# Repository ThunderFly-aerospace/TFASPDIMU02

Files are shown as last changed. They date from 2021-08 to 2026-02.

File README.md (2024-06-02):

# TFASPDIMU02 - Differential pressure sensor and IMU



ThunderFly TFASPDIMU02 is I2C bus sensor board equipped with a differential pressure sensor ([Sensirion SDP3x](https://www.sensirion.com/sdp3x/)) and 9-axis motion tracking sensor ([ICM-20948](https://invensense.tdk.com/products/motion-tracking/9-axis/icm-20948/)). The board is equipped with a 4-pin JST-GH connector. The sensor board is designed for multiple uses. It can be used as a self-adjusting anemometer [WINDGAUGE03](https://github.com/mlab-modules/WINDGAUGE03) or as an airspeed sensor for UAVs with optional function as the external magnetometer. The featured use (after firmware improvement) could be an angle of attract sensor, stall detector, or vibration (Flutter) detector.

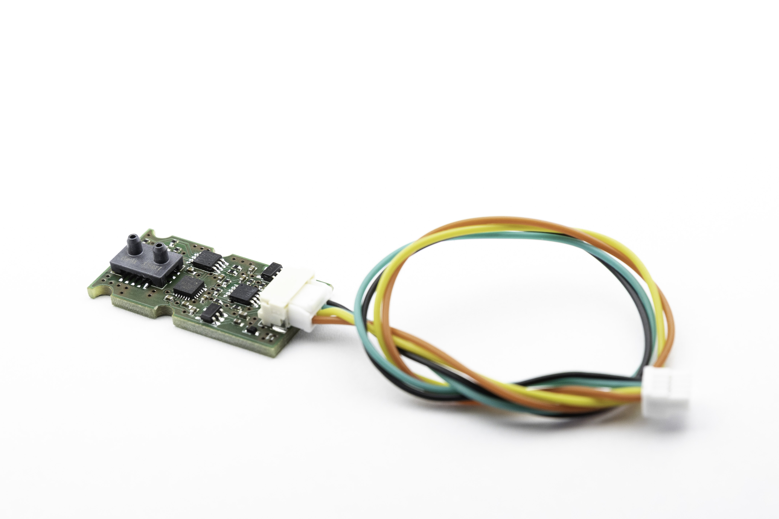
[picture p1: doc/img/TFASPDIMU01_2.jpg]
TFASPDIMU02 PCB


TFASPDIMU is commercially available from [ThunderFly s.r.o.](https://www.thunderfly.cz/), write an email to info@thunderfly.cz or shop at [Tindie store](https://www.tindie.com/stores/thunderfly/).

## Specification
 * Type: Differential and 9-axis motion sensor board
 * Mass: 3 g
 * Size: 30 x 15 mm
 * Power input: +5 V
 * Connection: 4pin JST-GH connector PixHawk compatible

**SDP3x differential pressure sensor**
 * Range: +/- 125/500/1500 Pa (depending on exact sensor type [SDP33 by default](https://sensirion.com/media/documents/6B7302AA/6375F33C/DP_DS_SDP33_D1.pdf))
 * Excellent accuracy and repeatability, even below one Pascal
 * No zero-point offset, no temperature drift
 * Calibrated and temperature-compensated
 * Fast sampling time of 2kHz at 16 bit resolution
 * I2C address: 0x21 (0d33), could be changed by JP2 and/or resorderig the R10 value.

 **ICM-20948 9-axis IMU unit**
 * 3-axis gyroscope, 3-axis accelerometer, 3-axis compass (magnetometer)
 * Onboard Digital Motion Processor (DMP)
 * On-chip 16-bit ADCs and Programmable Filters
 * 7 MHz SPI or 400 kHz Fast Mode I²C
 * Digital temperature sensor
 * Default I2C address: 0x68 (0d104), can be changed to 0x69 (0d105) by adjusting the JP1.

## Example of uses

### WINDGUAGE - weather vane sensor 

Ground control station anemometer [WINDGAUGE03](https://github.com/mlab-modules/WINDGAUGE03) is based on a TFASPDIMU sensor which is used for both wind direction and wind speed measurement. 

### TFSLOT01 - UAV airspeed sensor

Our [TFSLOT](https://github.com/ThunderFly-aerospace/TFSLOT01) sensor is an airspeed sensor for use mainly on UAVs. Due to the 3D printed case, optimizing housing according to the sensor's location on the UAV and tuning its characteristics is possible. The first use of this sensor was on our autogyro [TF-G2](https://github.com/ThunderFly-aerospace/TF-G2/).

TFSLOT01 sensor

More details about this solution are available in the repository [TFSLOT01](https://github.com/ThunderFly-aerospace/TFSLOT01).

### TFPIPE01 - UAV airspeed sensor

The symmetric variant of TFSLOT sensor for different mounting options [TFPIPE01](https://github.com/ThunderFly-aerospace/TFPIPE01).

### TFVENTUFO - innovative anemometer

This anemometer is also based on the venturi effect. Thanks to a clever design, it will measure the wind speed from all directions (without knowing the direction).

### Angle of Attack sensor

In case of mounting on slip-ring bearing the sensor could sense air AoA of the vehicle.

### Stall detector

The venturi geometry could also be inverted therefore the pressure ports look in open airflow. That results in the ability to detect stalls on wings by detecting the absence of pressure difference and increasing pressure fluctuations on the wing surface. 

## Hardware

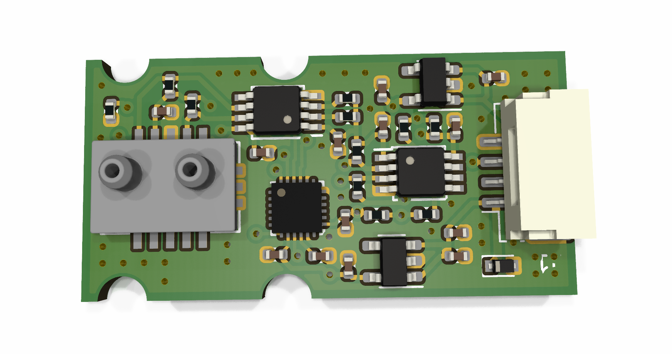
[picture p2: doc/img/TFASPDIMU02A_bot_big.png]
TFASPDIMU02 PCB


### Electronics schema

Full schema is available in [PDF](/hw/sch_pcb/TFASPDIMU02A.pdf)
TFASPDIMU02 schema

### PCB dimensions

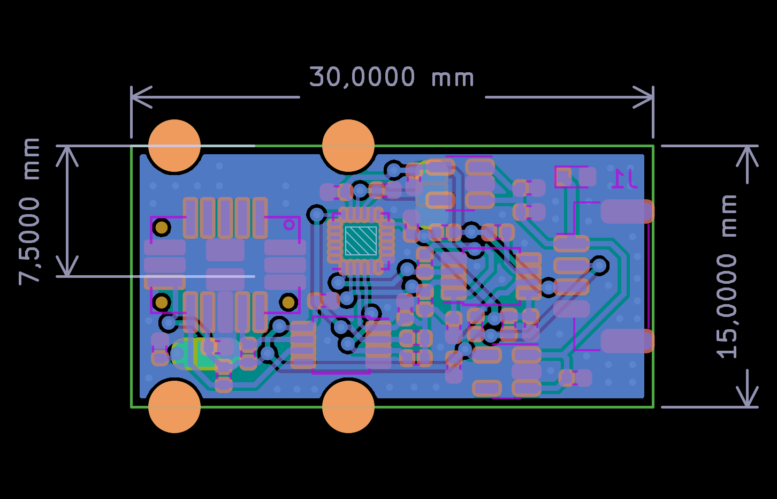
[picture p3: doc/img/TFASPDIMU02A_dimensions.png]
TFASPDIMU02 dimensions


Pressure sensor connections are aligned to the center of the PCB width.

### I2C connector pinout

|Signal | Pixhawk Color | ThunderFly color |
|---|---|---|
| +5V  | Red | red Red |
| SCL  | Black |  yellow Yellow |
| SDA  | Black |  green Green |
| GND | Black | black Black |

> Pixhawk pinout is listed according to the [Pixhawk connector standard](https://github.com/pixhawk/Pixhawk-Standards/blob/master/DS-009%20Pixhawk%20Connector%20Standard.pdf).

#### PixHawk autopilot connection cable

To increase the transmission quality, it is mandatory to create twisted pairs of SDA, GND, and SCL,+5V on the cable (as shown in the image)

- 10 twists for each pair  SCL/+5V and SDA/GND per 30cm cable length
- 4 turns/twists of pairs per 30cm cable length.

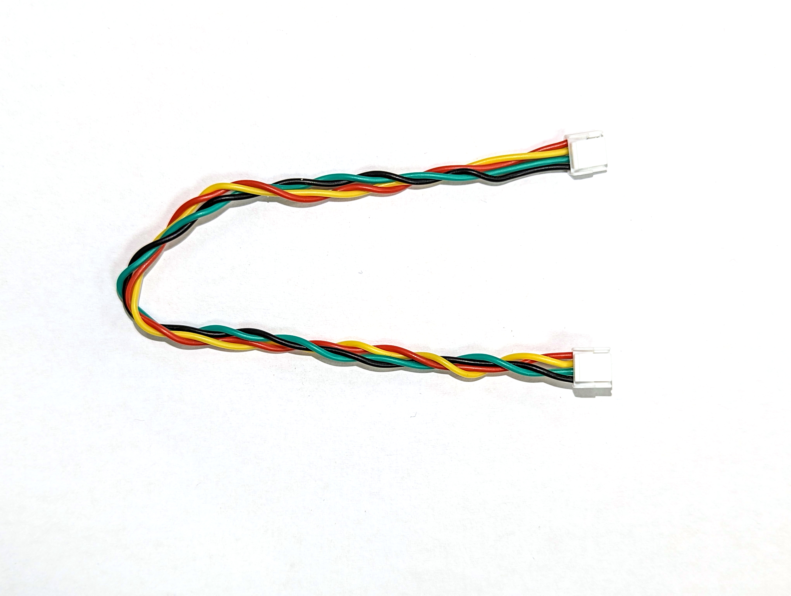
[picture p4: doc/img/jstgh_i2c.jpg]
ThunderFly I2C jstgh


## Usage

### Python
For reading data from the sensor, we have prepared a Python script in the [PyMLAB](https://github.com/MLAB-project/pymlab) library that uses the pySMBus to read data. It can be used directly from a computer with a corresponding converter (for example MLAB [USBI2C01A](https://wiki.mlab.cz/doku.php?id=cs:usbi2c)) or with one-board computers (Odroid, raspberry, and similar) that have own smbus output.

#### Calibration verification

Calibration can be verified by mounting an anemometer to the car roof and comparing it to GNSS speed. This needs to be done in windless weather.

### PX4

> There exists a [pull-request of modified SDP33 driver into PX4 stack](https://github.com/PX4/PX4-Autopilot/pull/18593).

The main use of this sensor is as an airspeed sensor. It can also be used as an external magnetometer and thermometer.

### Ardupilot

We are currently unable to implement the sensor in the Ardupilot flight stack. However, we will be happy to assist with implementation. You can [contact us](https://www.thunderfly.cz/contact-us.html)

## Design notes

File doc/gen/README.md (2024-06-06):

# PCB

Board size: 30.0x15.0 mm (1.18x0.59 inches)

- This is the size of the rectangle that contains the board
- Thickness: 1.6 mm (63 mils)
- Material: FR4
- Finish: HAL lead-free
- Layers: 2
- Copper thickness: 35 µm

Solder mask: TOP / BOTTOM

- Color: Green

Silk screen: TOP / BOTTOM

- Color: White

Stackup:

| Name | Type | Color | Thickness | Material | Epsilon_r | Loss tangent |
|---|---|---|---|---|---|---|
| F.SilkS | Top Silk Screen | | | | | |
| F.Paste | Top Solder Paste | | | | | |
| F.Mask | Top Solder Mask | Green | 10 | | | |
| F.Cu | copper | | 35 | | | |
| dielectric 1 | core | | 1510 | FR4 | 4.5 | 0.020 |
| B.Cu | copper | | 35 | | | |
| B.Mask | Bottom Solder Mask | Green | 10 | | | |
| B.Paste | Bottom Solder Paste  | | | | | |
| B.SilkS | Bottom Silk Screen | | | | | |

# Important sizes

Clearance: 0.2 mm (8 mils)

Track width: 0.2 mm (8 mils)

- By design rules: 0.2 mm (8 mils)

Drill: 0.5 mm (20 mils)

- Vias: 0.5 mm (20 mils) [Design: 0.4 mm (16 mils)]
- Pads: 0.7 mm (28 mils)
- The above values are real drill sizes, they add 0.1 mm (4 mils) to plated holes (PTH)

Via: 0.8/0.4 mm (31/16 mils)

- By design rules: 0.8/0.3 mm (31/12 mils)
- Micro via: yes [0.2/0.1 mm (8/4 mils)]
- Buried/blind via: yes
- Total: 70 (thru: 70 buried/blind: 0 micro: 0)

Outer Annular Ring: 0.15 mm (6 mils)

- By design rules: N/A mm (N/A mils)

Eurocircuits class: 4B
- Using min drill 0.5 mm for an OAR of 0.15 mm

# General stats

Components count: (SMD/THT)

- Top: 0/4 (THT)
- Bottom: 36/0 (SMD)

Defined tracks:

- 0.2 mm (8 mils)
- 0.3 mm (12 mils)
- 0.4 mm (16 mils)
- 0.5 mm (20 mils)
- 0.6 mm (24 mils)
- 0.7 mm (28 mils)
- 0.8 mm (31 mils)

Used tracks:

- 0.2 mm (8 mils) (39) defined: yes
- 0.3 mm (12 mils) (184) defined: yes
- 0.4 mm (16 mils) (23) defined: yes
- 0.5 mm (20 mils) (3) defined: yes

Defined vias:

Used vias:

- 0.8/0.4 mm (31/16 mils) (Count: 70, Aspect: 2.0 A) defined: no

Holes (excluding vias):

- 0.7 mm (28 mils) (3)
- 3.0 mm (118 mils) (4)

Oval holes:

Drill tools (including vias and computing adjusts and rounding):

- 0.5 mm (20 mils) (70)
- 0.7 mm (28 mils) (3)
- 3.0 mm (118 mils) (4)

Solder paste stats:

Using a paste with 87.75 % alloy, that has an specific gravity for the alloy of 7.4 g/cm³
and 1.0 g/cm³ for the flux. This paste has an specific gravity of  4.15 g/cm³.

The stencil thickness is  0.12 mm.

| Side | Pads with paste | Area [mm²] | Paste [g] |
|---|---|---|---|
| Total  | 128 | 65.00 | 0.32 |

Note: this is just an approximation to the theoretical value. Margins of the solder mask and waste aren't computed.

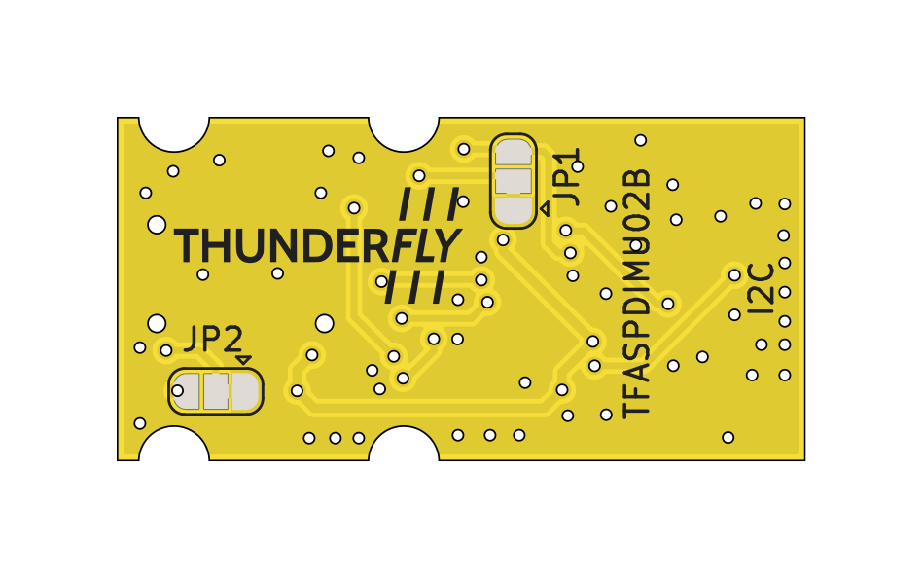
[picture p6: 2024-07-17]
doc/gen/img/TFASPDIMU02-top.png

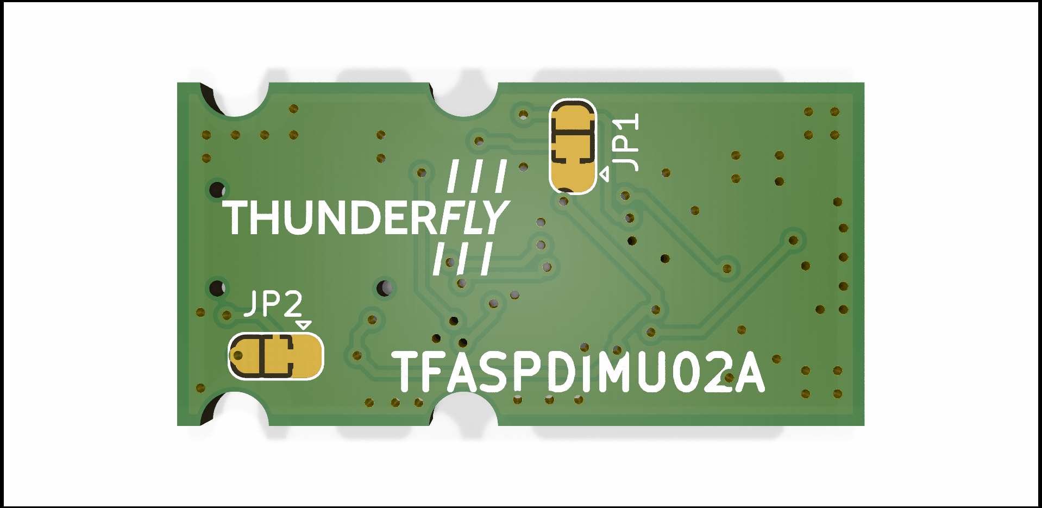
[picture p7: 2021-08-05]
doc/img/TFASPDIMU02A_top_big.png

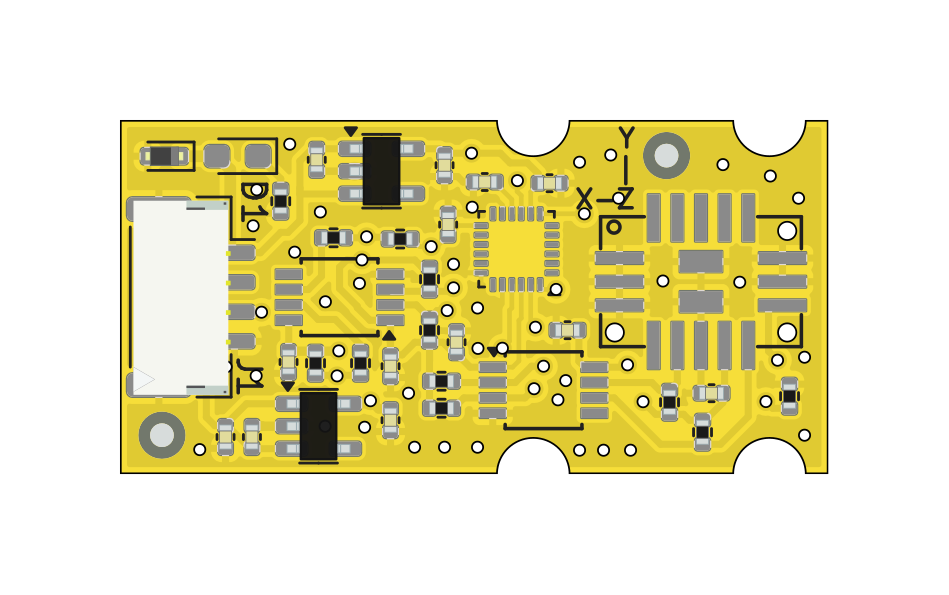
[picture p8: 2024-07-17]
doc/gen/img/TFASPDIMU02-bottom.png

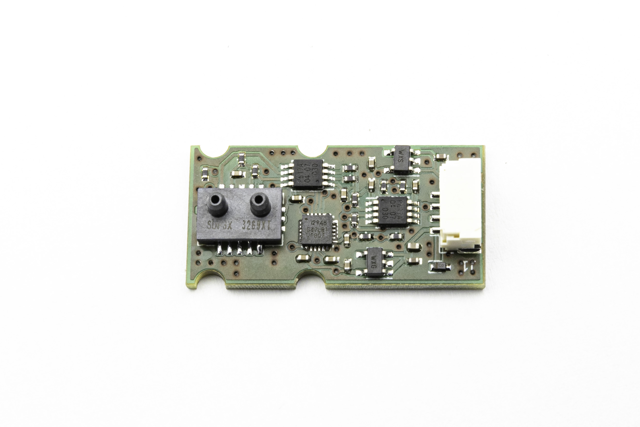
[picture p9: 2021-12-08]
doc/img/TFASPDIMU01_3.jpg

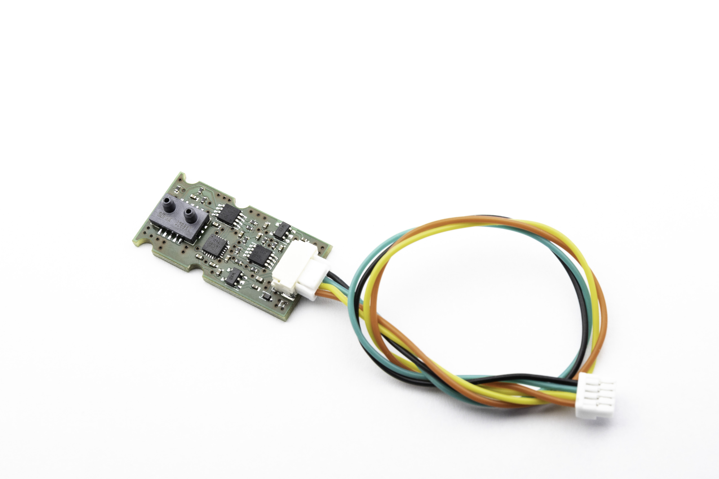
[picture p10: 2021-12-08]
doc/img/TFASPDIMU01_1.jpg

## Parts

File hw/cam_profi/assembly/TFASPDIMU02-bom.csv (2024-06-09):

Component | Description | Part | References | Value | Footprint | Quantity Per PCB | Datasheet | ust_id
1 | Unpolarized capacitor | C | C1C2C3C4C9C10C12C13 | 100nF | C_0402_1005Metric | 8 | ~ | 5c70984812875079b91f8bdb
2 | Unpolarized capacitor | C | C5C6C7C8 | 1uF | C_0402_1005Metric | 4 | ~ | 610cff5e1287500165a96ff9
3 | Unpolarized capacitor | C | C11 | 10uF | C_0402_1005Metric | 1 | ~ | 610d01671287500165a97012
4 |  | D_ZENER | D2 | BZX585-B5V6.115 | D_SOD-523 | 1 |  | 60879d38128750769ee58e48
5 | Light emitting diode | LED | D1 | GREEN | LED_0603_1608Metric_Pad1.05x0.95mm_HandSolder | 1 | https://trgkey.com/sites/default/files/data-sheet/FYLS-0603UGC-6241.pdf | 60d582331287500165f859d0
6 | 1x05 2.54 mm pitch header | SM04B-GHS-TB | J1 | SM04B-GHS-TB | JST_GH_SM04B-GHS-TB_1x04-1MP_P1.25mm_Horizontal | 1 |  | 5c86273d1287500b4e0280be
7 | Resistor | R | R1R11 | 75R | R_0402_1005Metric | 2 | ~ | 610d02e21287500165a97051
8 | Resistor | R | R12 | 180R | R_0402_1005Metric | 1 | ~ | 66660d02fb0c4b90204330d4
9 | Resistor | R | R2R3R10 | 2k7 | R_0402_1005Metric | 3 | ~ | 610d02801287500165a9703c
10 | Resistor | R | R4R5R6R7R8R9 | 10k | R_0402_1005Metric | 6 | ~ | 5c70984512875079b91f894c
11 | InvenSense 9-Axis Motion Sensor, Accelerometer, Gyroscope, Compass, I2C/SPI, QFN-24 | ICM-20948 | U2 | ICM-20948 | InvenSense_QFN-24_3x3mm_P0.4mm | 1 | http://www.invensense.com/wp-content/uploads/2016/06/DS-000189-ICM-20948-v1.3.pdf | 5c725a431287500b4e112ef5
12 | 300mA Low-dropout Voltage Regulator, Vout 1.8V, Vin up to 5.5V, SOT-23 | MIC5504-1.8YM5 | U5 | MIC5504-1.8YM5-TR | SOT-23-5 | 1 | http://ww1.microchip.com/downloads/en/DeviceDoc/MIC550X.pdf | 5c7256781287500b4e112eba
13 | 300mA Low-dropout Voltage Regulator, Vout 3.3V, Vin up to 5.5V, SOT-23 | MIC5504-3.3YM5 | U4 | MIC5504-3.3YM5-TR | SOT-23-5 | 1 | http://ww1.microchip.com/downloads/en/DeviceDoc/MIC550X.pdf | 5c7255e81287500b4e112ea2
14 | Level-Translating I2C Bus Buffer/Repeater, TSSOP-8 | PCA9617A | U3U6 | PCA9617A | TSSOP-8_3x3mm_P0.65mm | 2 | https://www.nxp.com/docs/en/data-sheet/PCA9617A.pdf | 610d03ad1287500165a97076
15 |  | SDP3x | U1 | SDP3x | SDP3x | 1 | https://docs.rs-online.com/3cff/0900766b81643b7b.pdf | 5e32e1111287502a337d0b08

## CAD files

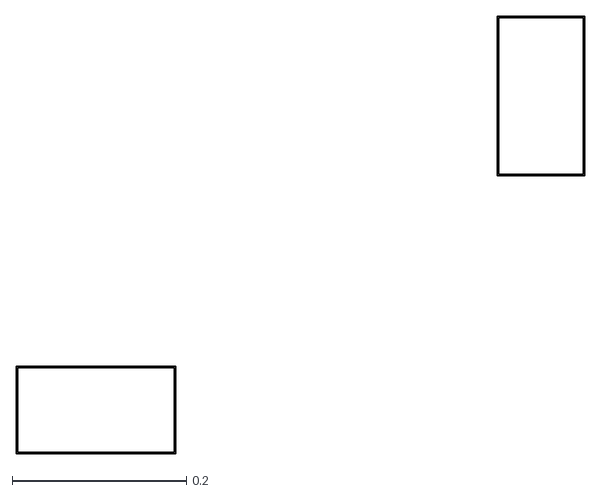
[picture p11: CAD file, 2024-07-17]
doc/gen/dxf/TFASPDIMU02-F_Courtyard.dxf
0.652 x 0.502

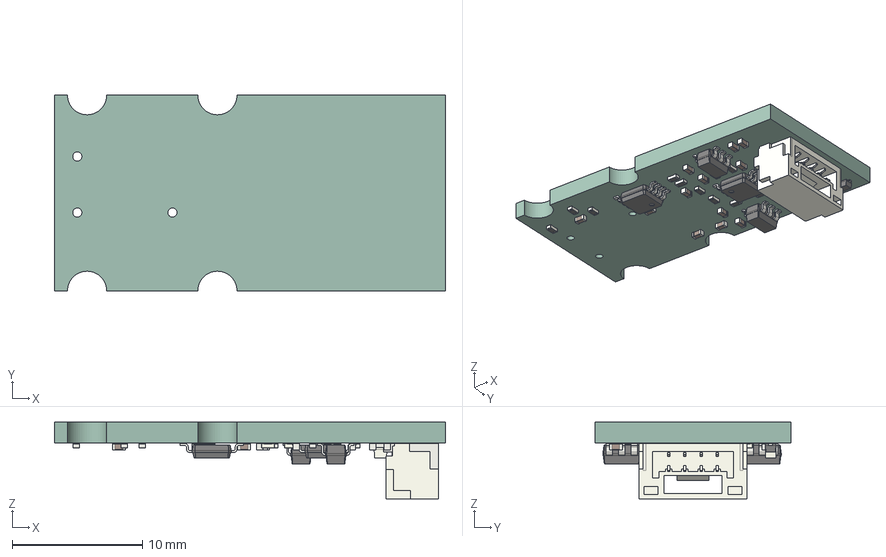
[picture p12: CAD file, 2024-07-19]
doc/gen/TFASPDIMU02.step
30.0 x 15.0 x 5.89 mm
C_0402_1005Metric x 13
R_0402_1005Metric x 12
D_SOD_523
TSSOP_8_3x3mm_P065mm x 2
LED_0603_1608Metric
JST_SM04B_GHS_TB
SOT_23_5 x 2
kibot_pvs4hcoh_PCB

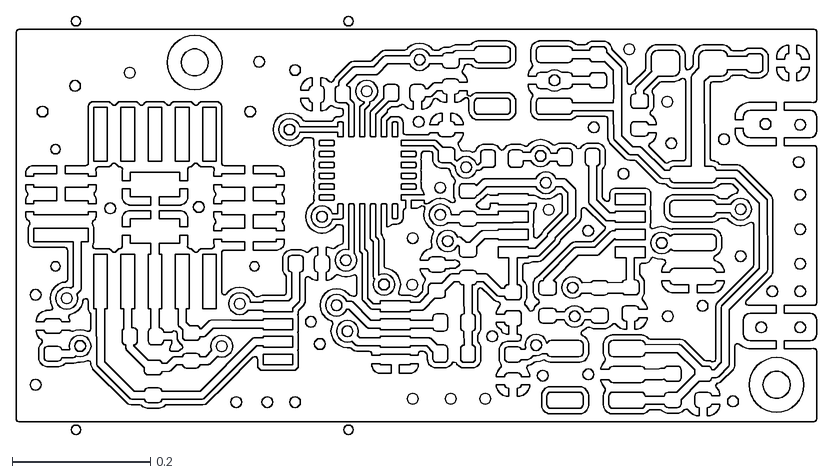
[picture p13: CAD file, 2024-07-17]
doc/gen/dxf/TFASPDIMU02-B_Cu.dxf
1.16 x 0.604

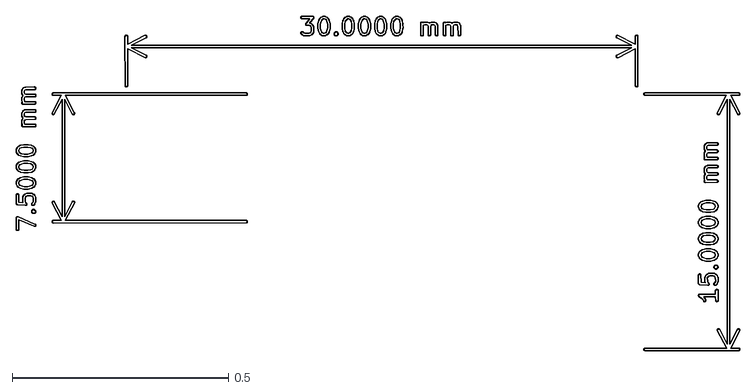
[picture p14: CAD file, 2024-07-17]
doc/gen/dxf/TFASPDIMU02-User_Drawings.dxf
1.67 x 0.773

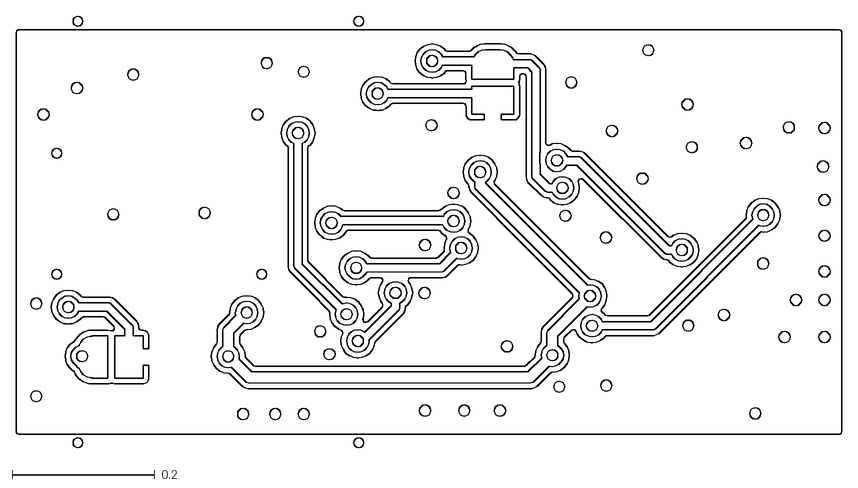
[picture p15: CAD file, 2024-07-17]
doc/gen/dxf/TFASPDIMU02-F_Cu.dxf
1.16 x 0.604

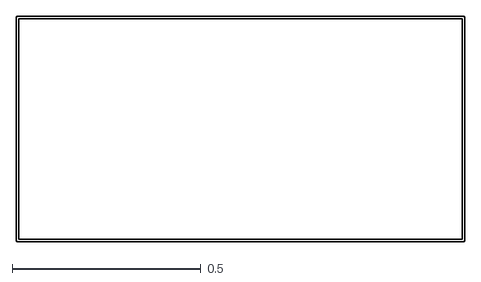
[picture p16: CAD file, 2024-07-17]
doc/gen/dxf/TFASPDIMU02-Edge_Cuts.dxf
1.19 x 0.596

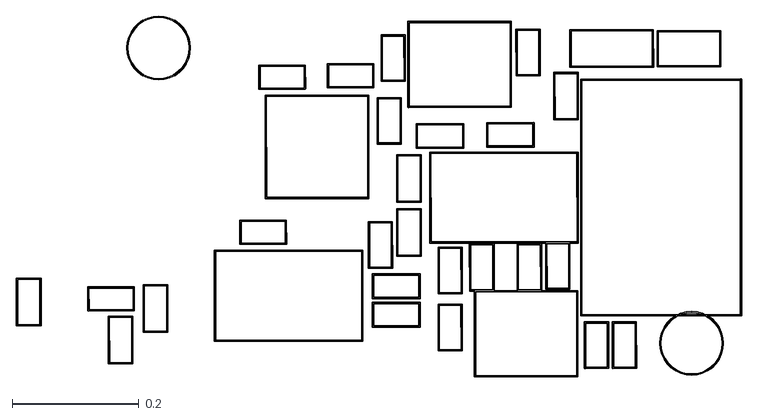
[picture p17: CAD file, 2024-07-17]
doc/gen/dxf/TFASPDIMU02-B_Courtyard.dxf
1.14 x 0.569

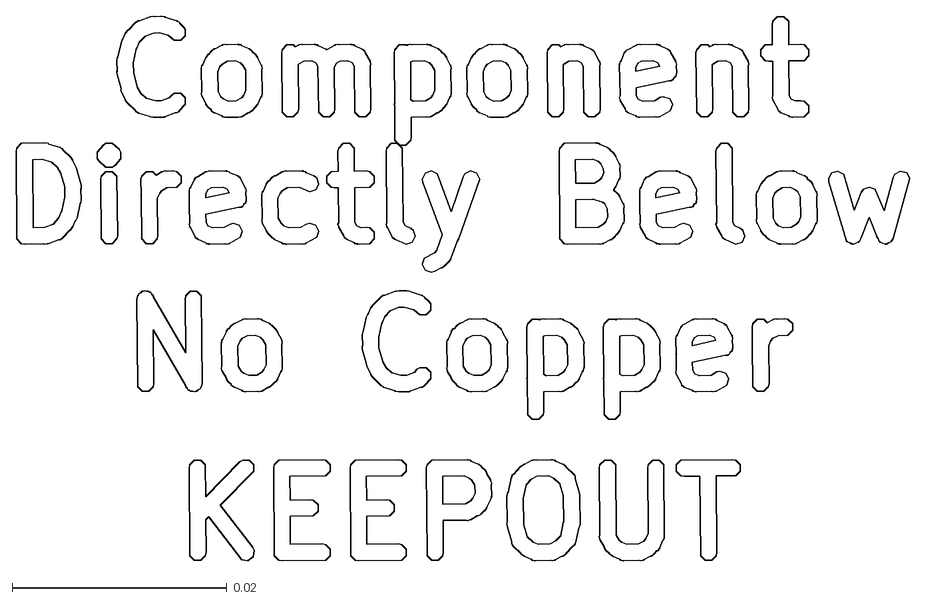
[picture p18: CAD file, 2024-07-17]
doc/gen/dxf/TFASPDIMU02-User_Comments.dxf
0.0833 x 0.0508

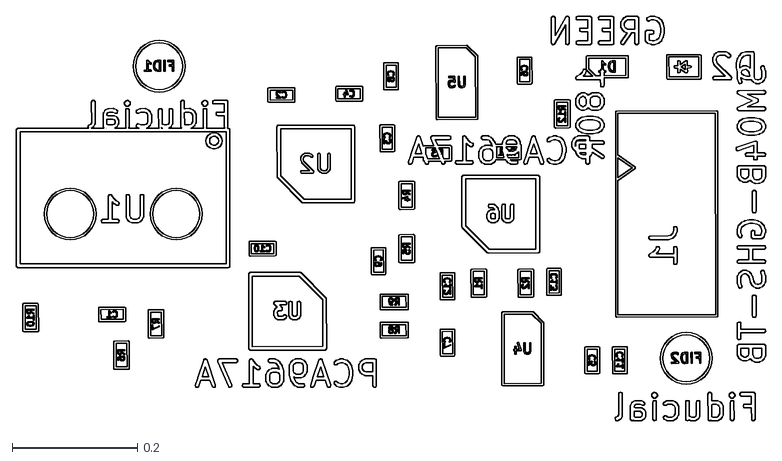
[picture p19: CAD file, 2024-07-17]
doc/gen/dxf/TFASPDIMU02-B_Fab.dxf
1.20 x 0.645

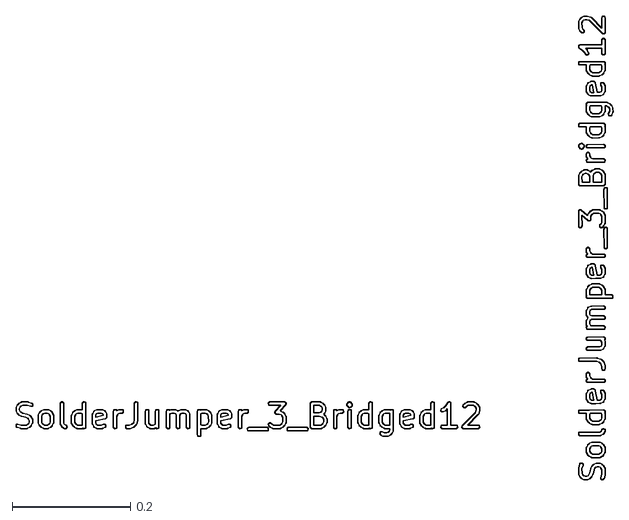
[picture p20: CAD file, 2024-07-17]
doc/gen/dxf/TFASPDIMU02-F_Fab.dxf
1.01 x 0.786

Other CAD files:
doc/gen/dxf/TFASPDIMU02-B_Adhesive.dxf
doc/gen/dxf/TFASPDIMU02-User_Eco2.dxf
doc/gen/dxf/TFASPDIMU02-F_Adhesive.dxf
doc/gen/dxf/TFASPDIMU02-Margin.dxf
doc/gen/dxf/TFASPDIMU02-User_Eco1.dxf
doc/gen/dxf/TFASPDIMU02-B_Mask.dxf
doc/gen/dxf/TFASPDIMU02-B_Paste.dxf
doc/gen/dxf/TFASPDIMU02-B_Silkscreen.dxf
doc/gen/dxf/TFASPDIMU02-F_Mask.dxf
doc/gen/dxf/TFASPDIMU02-F_Paste.dxf
doc/gen/dxf/TFASPDIMU02-F_Silkscreen.dxf

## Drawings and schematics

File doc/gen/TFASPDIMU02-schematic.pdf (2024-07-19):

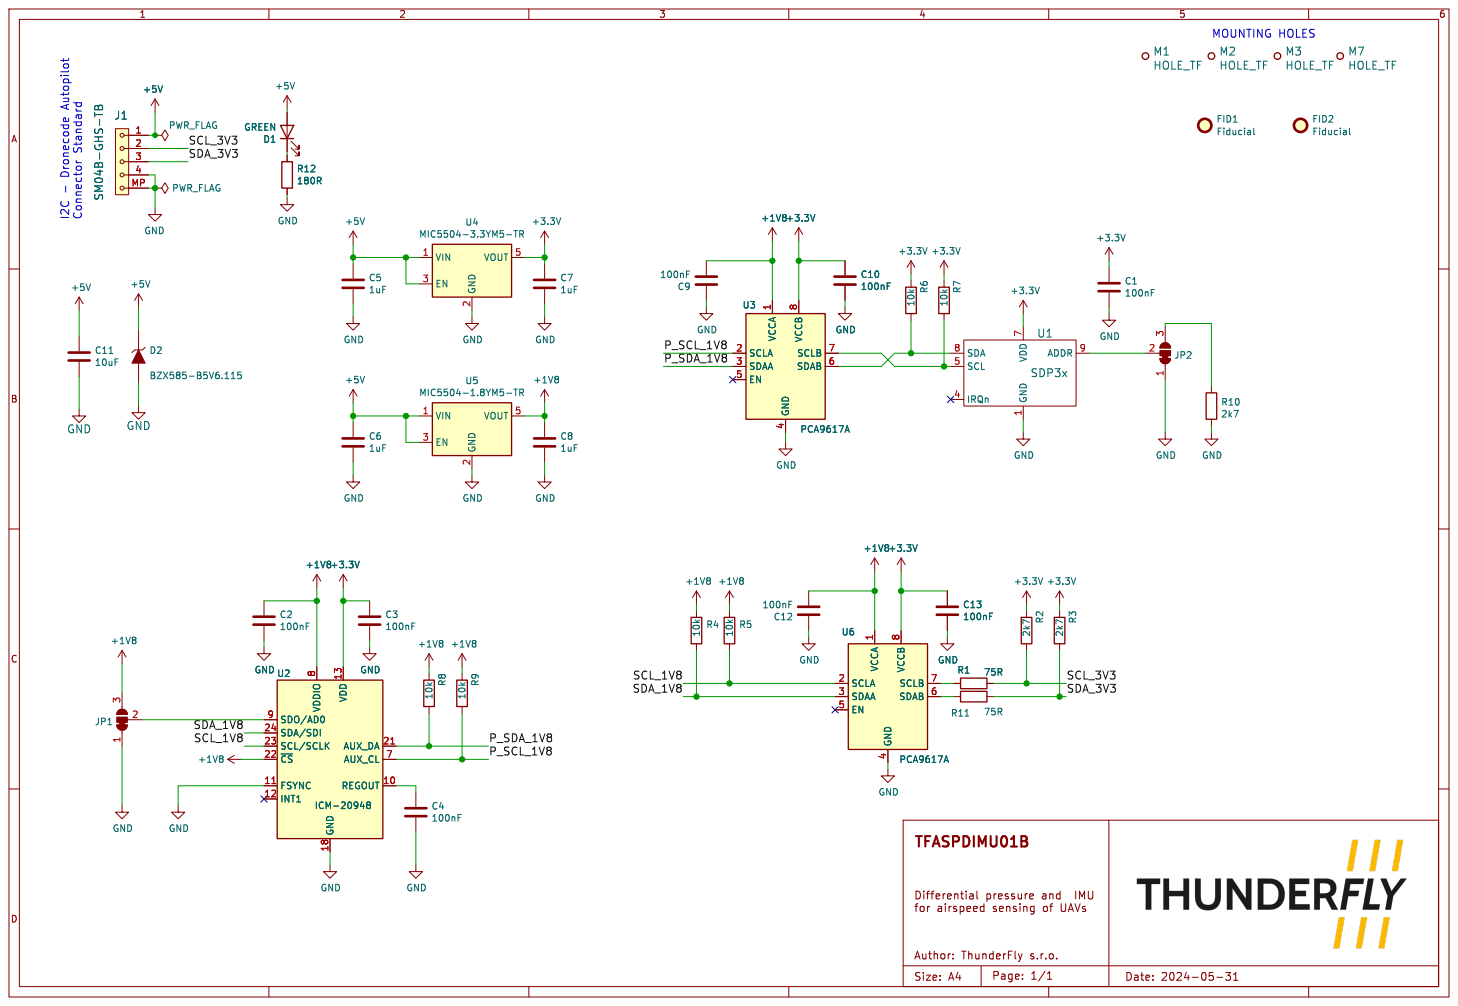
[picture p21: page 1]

4 EN 5 SDAB 6 SCLB 7 VCCB U3 8 PCA9617A

4 EN 5 SDAB 6 SCLB 7 VCCB

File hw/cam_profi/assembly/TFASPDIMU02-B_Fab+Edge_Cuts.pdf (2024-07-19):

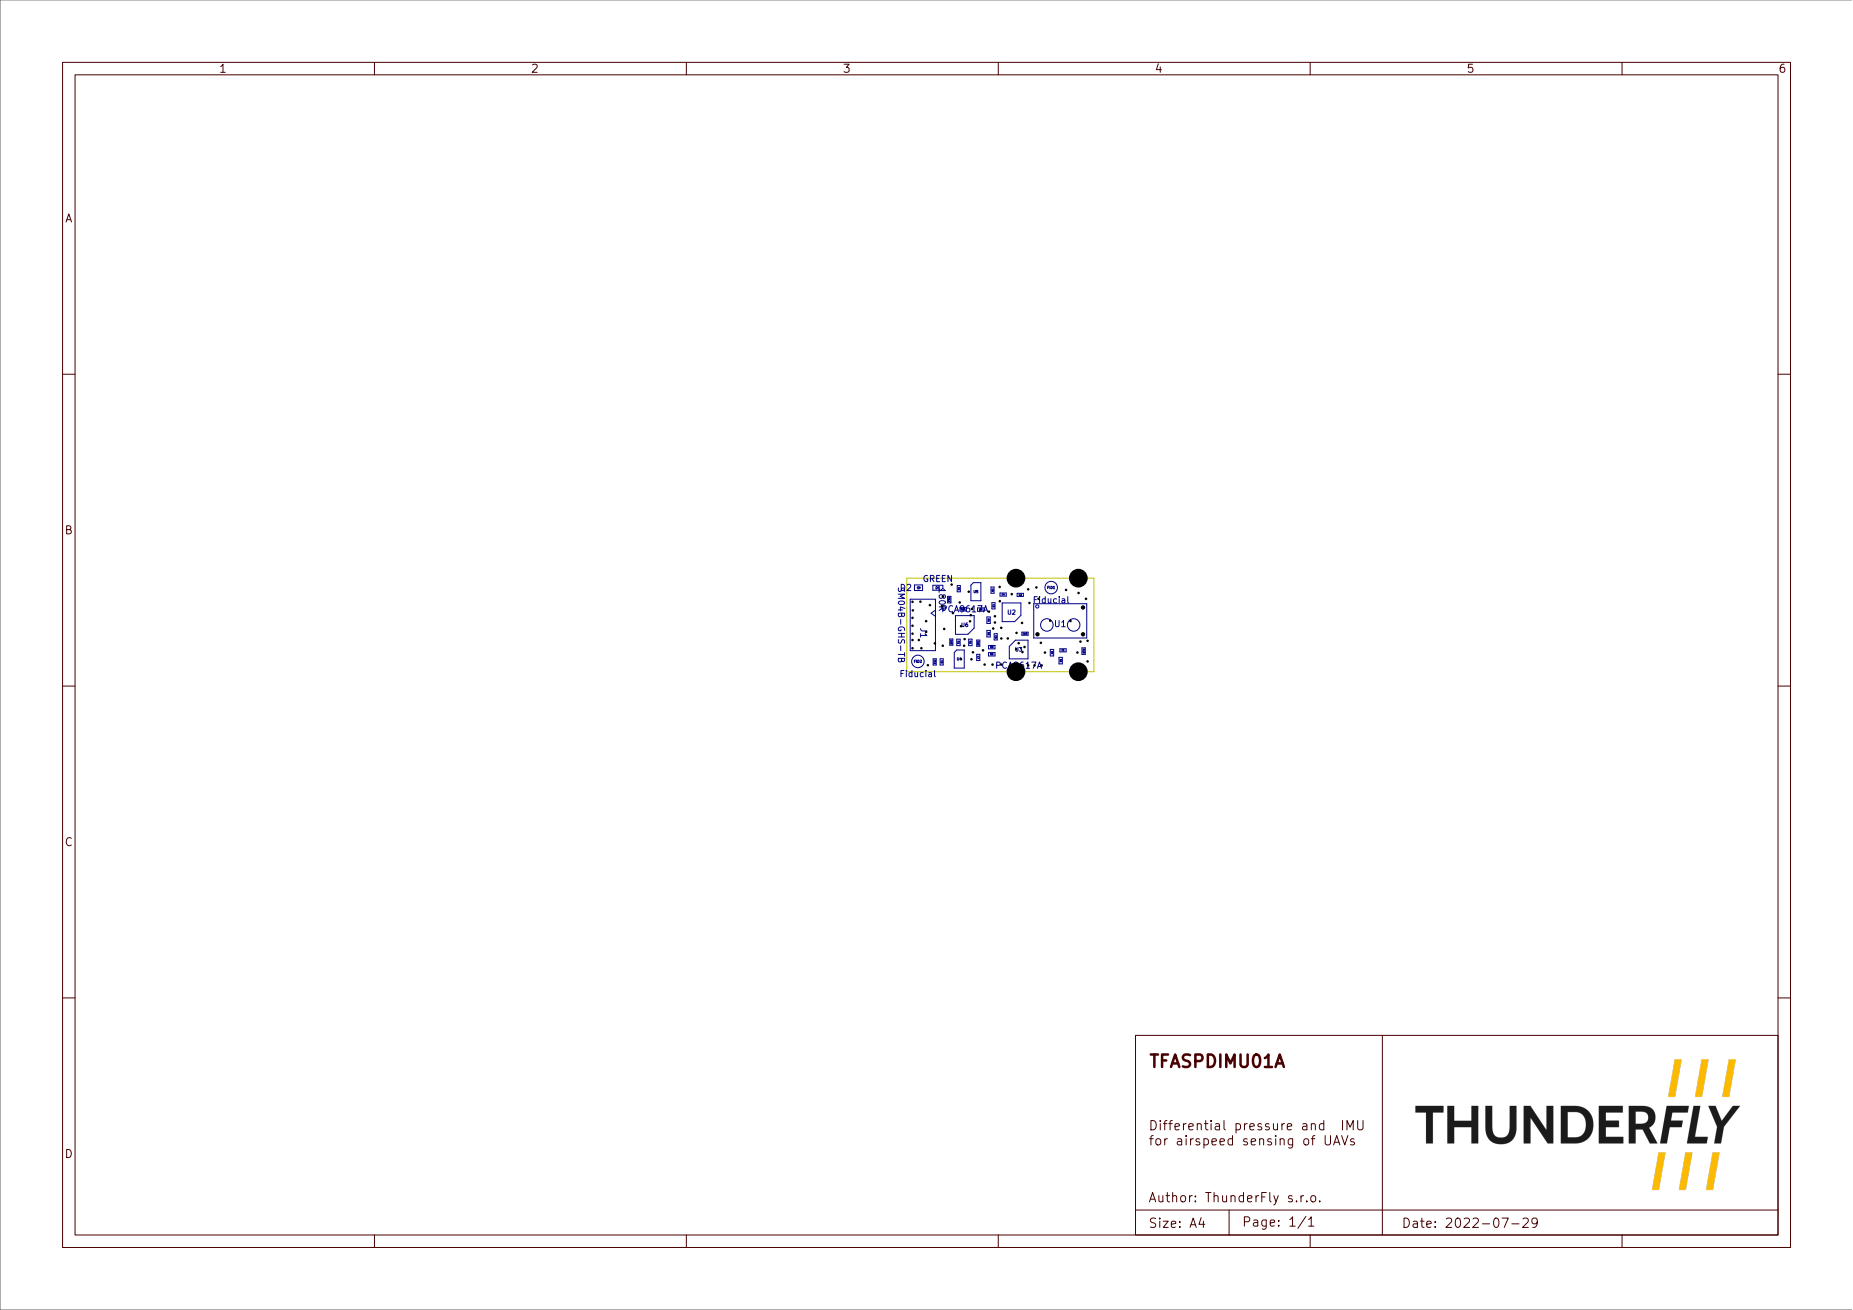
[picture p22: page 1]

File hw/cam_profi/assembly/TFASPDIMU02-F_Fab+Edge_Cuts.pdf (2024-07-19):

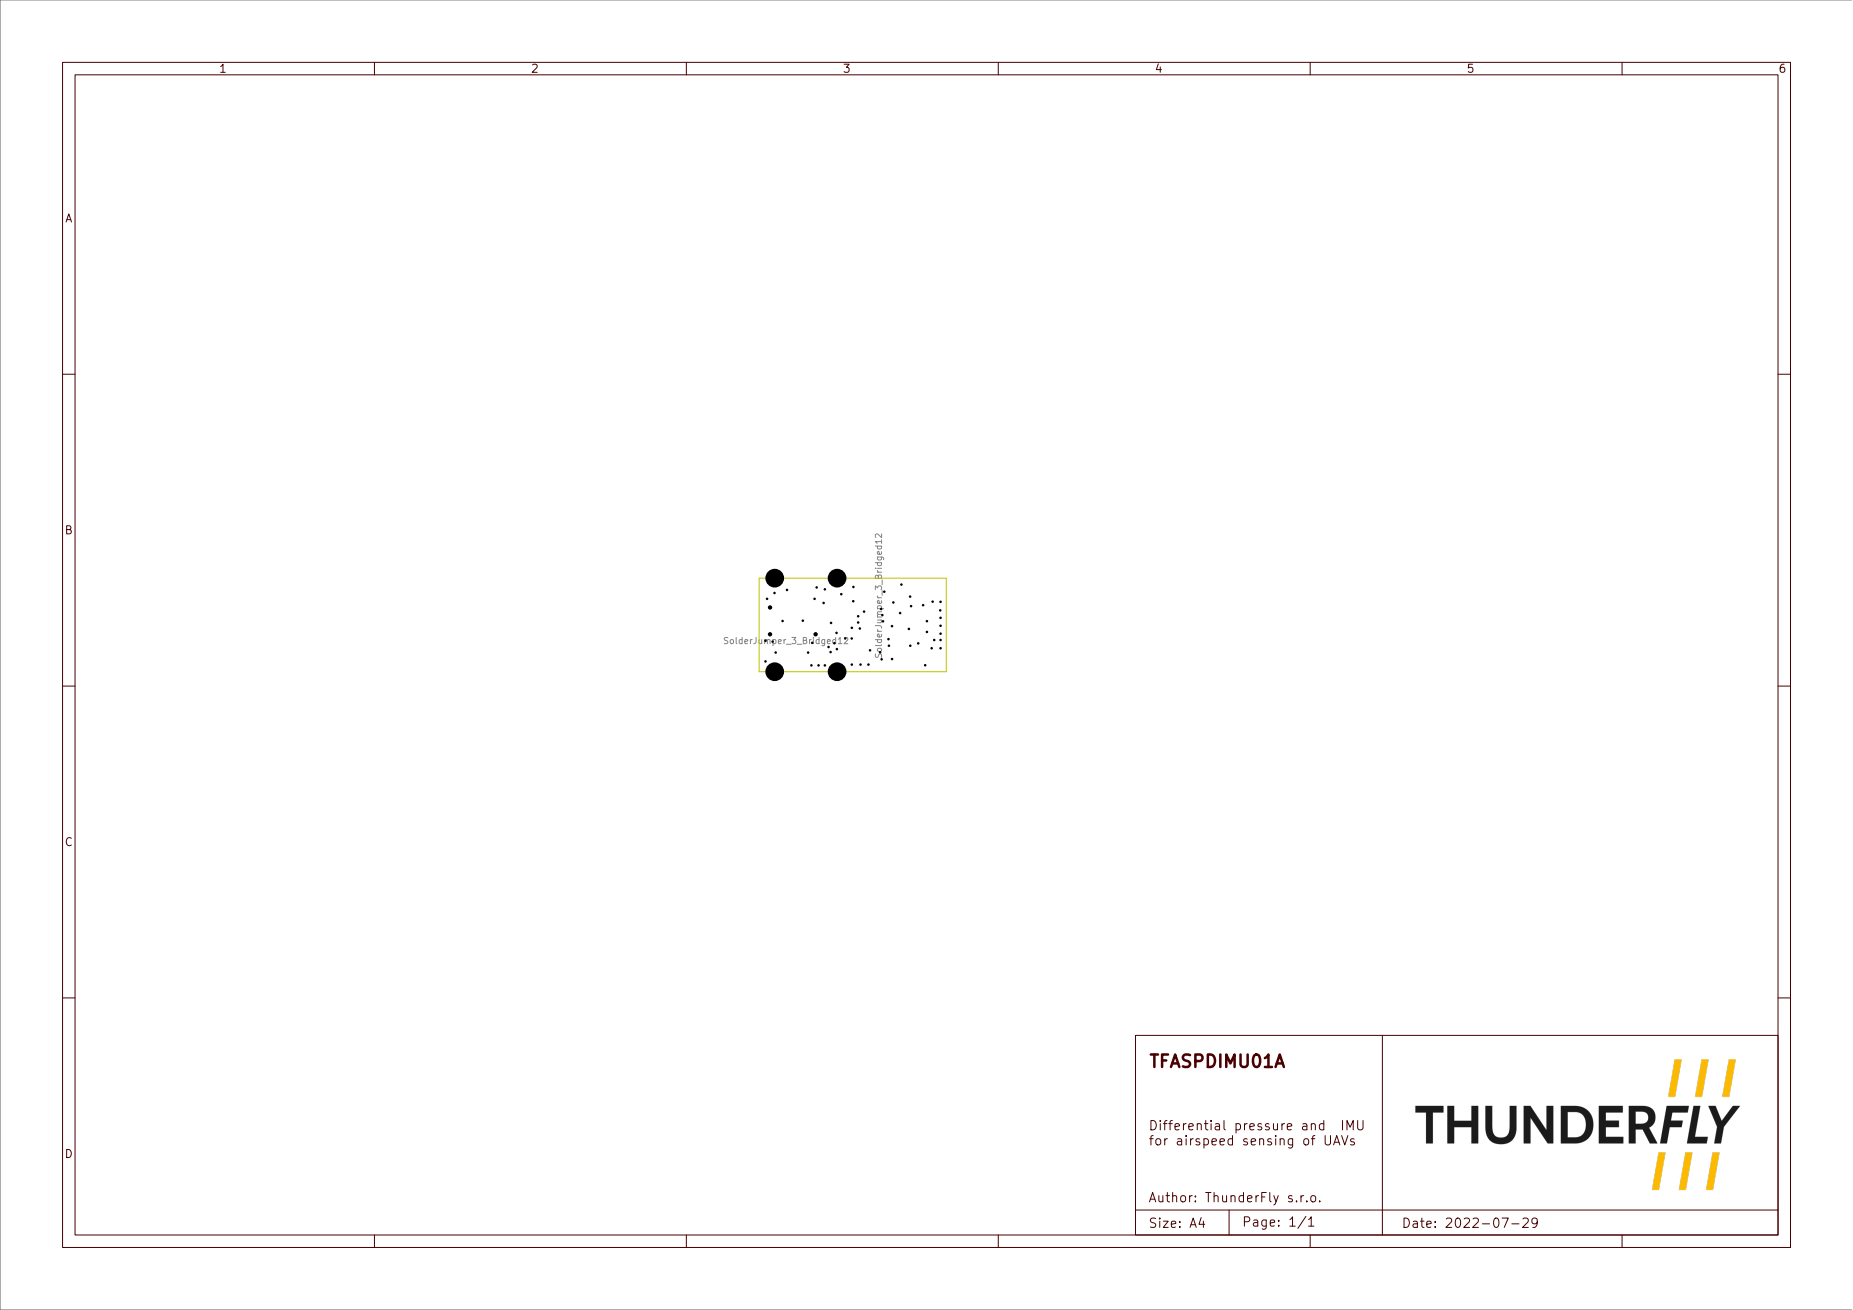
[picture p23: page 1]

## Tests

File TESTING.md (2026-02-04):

## Testovací procedura desky TFASPDIMU02

Deska obsahuje více senzorů. Všechny z nich je potřeba po výrobě otestovat. Následující postup popisuje, jak testování jednotlivých senzorů provádět. Pro toto testování je vhodné použít [pymlab skript](sw/pymlab/test_suite.py). 

### I2C komunikace
Komunikace po I2C se otestuje tím, že všechny z následující testy lze provést bez chyby. Pokud některý z testů selže je potřeba zkontrolovat správnost zapojení a ověřit jestli jsou všechny senzory viditelné na sběrnici například nástrojem `i2cdetect`. 

### SDP3x senzor
U airspeed senzoru se ověřuje, jestli při fouknutí do jedné z jeho trubiček se vytváří rozdíl tlaku. Toto měření je jen velmi orientační a zjišťuje funkčnost senzoru. Přesnější test je proveden ve finální aplikaci, kdy je senzor je vložen do odpovídajícího obalu. Tam se pak testuje i jeho dobré utěsnění. 

```
(.venv) TFASPDIMU02/sw/pymlab$ python3 test_suite.py 9 0
{'port': 9, 'device': 'hid'}
ID: 0x3010384 - sensor: SDP33 1500Pa
Magnetometer not calibrated.

0000; 2026-02-04T10:50:02.387614+00:00; Dp: +0.00 [Pa]; T: 29.467 [degC]; MAG_HDG: +56.41; SPD_W_DP: +0.00 [km/h]
0000; 2026-02-04T10:50:02.521622+00:00; Dp: +0.00 [Pa]; T: 29.611 [degC]; MAG_HDG: +55.76; SPD_W_DP: +0.00 [km/h]
0000; 2026-02-04T10:50:02.655617+00:00; Dp: +0.05 [Pa]; T: 29.563 [degC]; MAG_HDG: +55.50; SPD_W_DP: -0.08 [km/h]
0000; 2026-02-04T10:50:02.789611+00:00; Dp: +0.00 [Pa]; T: 29.563 [degC]; MAG_HDG: +55.18; SPD_W_DP: +0.00 [km/h]
0000; 2026-02-04T10:50:02.923609+00:00; Dp: +0.00 [Pa]; T: 29.372 [degC]; MAG_HDG: +55.25; SPD_W_DP: +0.00 [km/h]
0000; 2026-02-04T10:50:03.057605+00:00; Dp: +0.00 [Pa]; T: 29.563 [degC]; MAG_HDG: +55.04; SPD_W_DP: +0.00 [km/h]
0000; 2026-02-04T10:50:03.191574+00:00; Dp: -43.10 [Pa]; T: 29.563 [degC]; MAG_HDG: +54.88; SPD_W_DP: +2.36 [km/h]
0000; 2026-02-04T10:50:03.325599+00:00; Dp: -77.60 [Pa]; T: 29.467 [degC]; MAG_HDG: +54.78; SPD_W_DP: +3.17 [km/h]
0000; 2026-02-04T10:50:03.459580+00:00; Dp: -74.50 [Pa]; T: 29.611 [degC]; MAG_HDG: +54.74; SPD_W_DP: +3.11 [km/h]
0000; 2026-02-04T10:50:03.593552+00:00; Dp: -100.25 [Pa]; T: 29.419 [degC]; MAG_HDG: +54.65; SPD_W_DP: +3.60 [km/h]
0000; 2026-02-04T10:50:03.727543+00:00; Dp: -91.85 [Pa]; T: 29.563 [degC]; MAG_HDG: +54.57; SPD_W_DP: +3.45 [km/h]
0000; 2026-02-04T10:50:03.861543+00:00; Dp: -136.35 [Pa]; T: 29.467 [degC]; MAG_HDG: +54.48; SPD_W_DP: +4.20 [km/h]
0000; 2026-02-04T10:50:03.995534+00:00; Dp: -140.55 [Pa]; T: 29.611 [degC]; MAG_HDG: +55.69; SPD_W_DP: +4.27 [km/h]
0000; 2026-02-04T10:50:04.129526+00:00; Dp: -132.70 [Pa]; T: 29.611 [degC]; MAG_HDG: +56.82; SPD_W_DP: +4.15 [km/h]
```

### IMU jednotka
U imu jednotky se ověřují hodnoty, které jsou měřeny. 

```TODO: Není jasné jakým skriptem jsou následující testy provedeny```

#### Akcelorometr
Funkčnost akcelorometru se ověřuje tím, že indikované hodnoty náklonů pitch/roll jsou spávné. Je vhodné si senzor vzít na rovnou plochu. Při položení na tuto plochu by měl indikovat nulový náklon pitch/roll. 

Otáčením podle delší osy by se měly měnit hodnoty v ose roll. Při měření je vhodné si pomoct trojúhelníkovým pravítkem, podle kterého se PCB opře. V této poloze by senzor měl ukazovat hodnoty okolo 90deg. Vzhledem k tomu, že při tomto měření není senzor kalibrovaný, tak maximální hodnota může být nižší. Neměla by však být nižší než 85 deg. Běžně se s funkčním senzorem (bez kalibrace) dají změřit úhly okolo 89.8 deg. Stejný postup je potřeba zopakovat pro osu pitch (kolmo na podélnou osu senzoru). 

#### Magnetometr
U magnetometru je potřeba ověřit, že určený azimut odpovídá realitě, při pomalém kompletním otáčení se hodnota očekávatelně mění. Zde si lze pomoct buď úhloměrem nebo vytištěnou kružnicí na papíře s naznačenými úhly. Je také vhodné věřit opakovatelnost tohoto měření způsobem, že si na začátku zapamatujete určitou orientaci a měřený úhel. Na konci procedury tyto zapamatované hodnoty a aktuálni hodnoty sedí.

#### Gyroskop
U gyroskopu je možné ověřit, že v klidovém stavu ukazuje nulu. A pří pokusu o otočení v jedné ose tyto hodnoty zvětší a zase se vrátí na nulu.

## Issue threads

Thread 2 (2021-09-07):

EMC noise imunity

kaklik, 2021-09-07:
Rozebral jsem ten SDP33 senzor od DROTEKu.

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

Je tam několik zajímavých věcí.

- Nemají tam vůbec žádný pull-upy i přes to, že tam na ně mají místo.
- Zjevně se tam na několika místech snaží hodně bojovat s EMC. Mají tam průchodkový kondenzátory a zřejmě minimálně dvě tlumivky.

Usuzuju z toho, že ten senzor je citlivý na rušení v napájení.  Nebo v opačným případě okopírovali zapojení z toho původního analogovýho senzoru.
Každopádně by to možná mohlo vysvětlovat některý potíže, který s tím snímačem teď máme.

kaklik, 2024-05-30:
Další tlumivku ani průchodkový kondenzátor na PCB není kam dát. Takže jsem udělal jen to, že jsem jinak přivedl napájení a země.

Closed 2024-05-30.

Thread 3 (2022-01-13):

Simple airspeed sensor for pitot tube

kaklik, 2022-01-13:
The sensor PCB could be connected to a pitot tube.  Some suggestions of pitot-tube type and connection hoses could be helpful.
The optimal tubing outer diameter seems to be around 3mm.

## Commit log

2021-08-02 Edit schema
    [TFASPDIMU01B.kicad_pcb, TFASPDIMU01B.kicad_sch]
2021-08-02 Regenerate schematics PDF.
2021-08-03 Edit schema and PCB
    [TFASPDIMU01B.kicad_pcb, TFASPDIMU02A.kicad_pcb, TFASPDIMU02A.kicad_sch]
2021-08-04 Edit PCB
    [TFASPDIMU02A.kicad_pcb, TFASPDIMU02A.kicad_sch]
2021-08-04 Dimensions and layout improvement.
    [TFASPDIMU02A.kicad_pcb, TFASPDIMU02A.kicad_sch]
2021-08-05 Edit PCB. #1
    [TFASPDIMU02A.kicad_pcb, TFASPDIMU02A.kicad_sch]
2021-08-05 Layout and silkscreen improvements.
    [TFASPDIMU02A.kicad_pcb]
2021-08-06 Edit bom
    [TFASPDIMU02A.csv, TFASPDIMU02A.kicad_sch]
2021-08-10 Documentation update and fresh exports.
    [TFASPDIMU02A-B_Cu.gbr, TFASPDIMU02A-B_Mask.gbr, TFASPDIMU02A-B_Silkscreen.gbr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]
2021-08-17 Edit PCB labels and PCB 3D model
    [TFASPDIMU02A.kicad_pcb]
2021-08-17 Update SDP3x footprint.
    [TFASPDIMU02A.kicad_pcb]
2022-07-29 Update title block Move PCB to center of page Mark magnetometer orientation in silkscreen
    [TFASPDIMU02A.kicad_pcb, TFASPDIMU02A.kicad_sch]
2024-05-30 Branch the new revision and update project configuration and KiCAD version.
    [TFASPDIMU02.kicad_pcb, TFASPDIMU02.kicad_sch, TFASPDIMU02A.csv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]
2024-05-30 Update actions products
    [TFASPDIMU02-B_Adhesive.dxf, TFASPDIMU02-B_Courtyard.dxf, TFASPDIMU02-B_Cu.dxf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]
2024-05-30 Improved layout.
    [TFASPDIMU02.kicad_pcb, TFASPDIMU02.kicad_sch]
2024-06-02 footprint of translator changed to VSSOP.
    [TFASPDIMU02.kicad_pcb, TFASPDIMU02.kicad_sch]
2024-06-02 Revert TSSOP footprint.
    [TFASPDIMU02.kicad_pcb, TFASPDIMU02.kicad_sch]
2024-06-05 Implement power indicating LED.
    [TFASPDIMU02.kicad_pcb, TFASPDIMU02.kicad_sch]
2024-06-06 Update footprints from library. Improve layout Move I2C connector inside to PCB to meet manufacturing limits.
    [TFASPDIMU02.kicad_pcb]
2024-06-09 Fix component specification.
    [TFASPDIMU02.kicad_sch]
2024-06-09 Exclude some components from BOM.
    [TFASPDIMU02.kicad_sch]
2024-06-09 Exclude mechanical symbols from BOM.
    [TFASPDIMU02.kicad_sch]
